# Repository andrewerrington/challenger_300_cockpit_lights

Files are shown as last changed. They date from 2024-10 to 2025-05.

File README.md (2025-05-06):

# challenger_300_cockpit_lights
COCKPIT LIGHTS panels for Challenger 300

DXF files for making the panels. Pilot panel requires one dual concentric potentiometer, two regular potentiometers, and one SR16 2-pos rotary
switch. Also, OpenSCAD files for producing knobs.

Arduino code to interface with X-Plane is included.

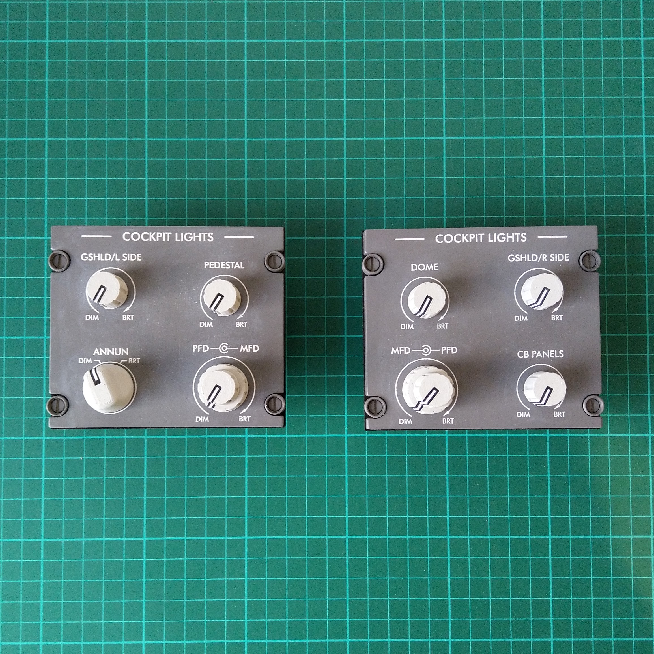
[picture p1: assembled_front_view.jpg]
Glamour shot of finished panels


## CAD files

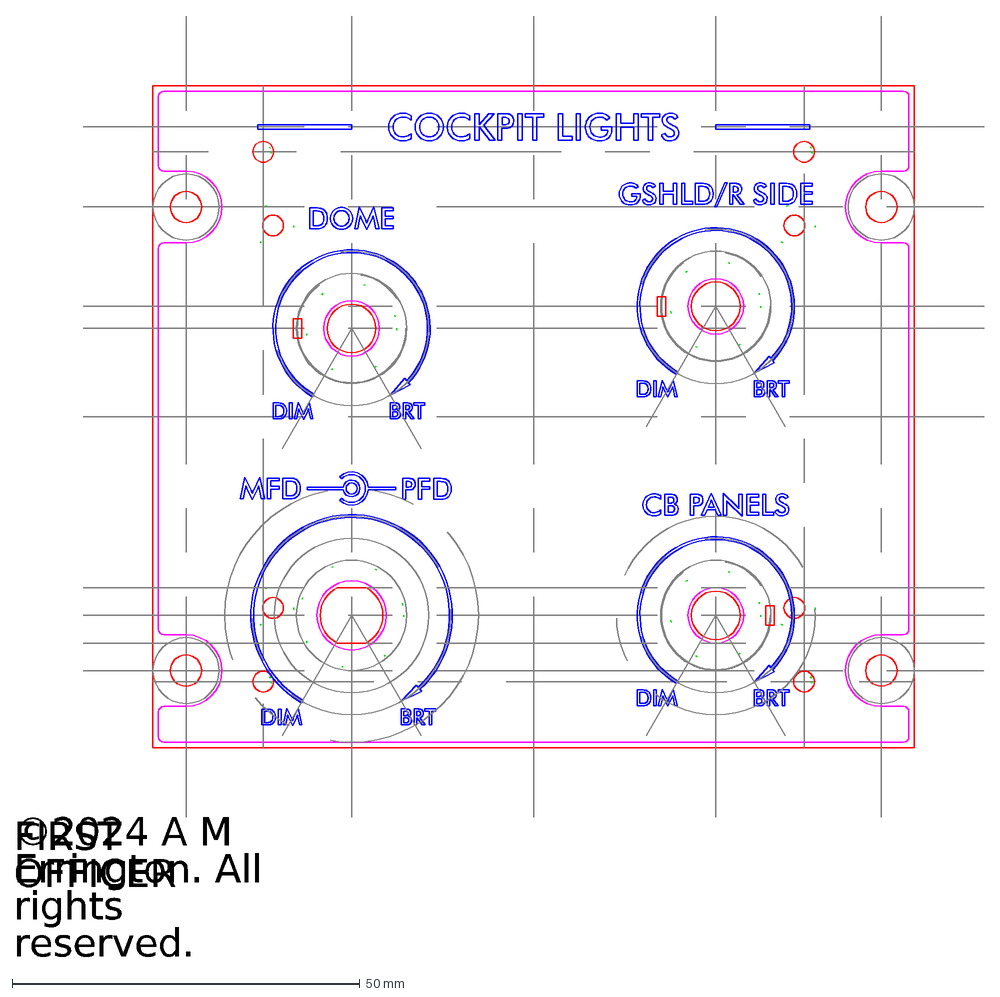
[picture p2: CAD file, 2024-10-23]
COCKPIT_LIGHTS_fo.dxf
FIRST OFFICER
©2024 A M Errington. All rights reserved.

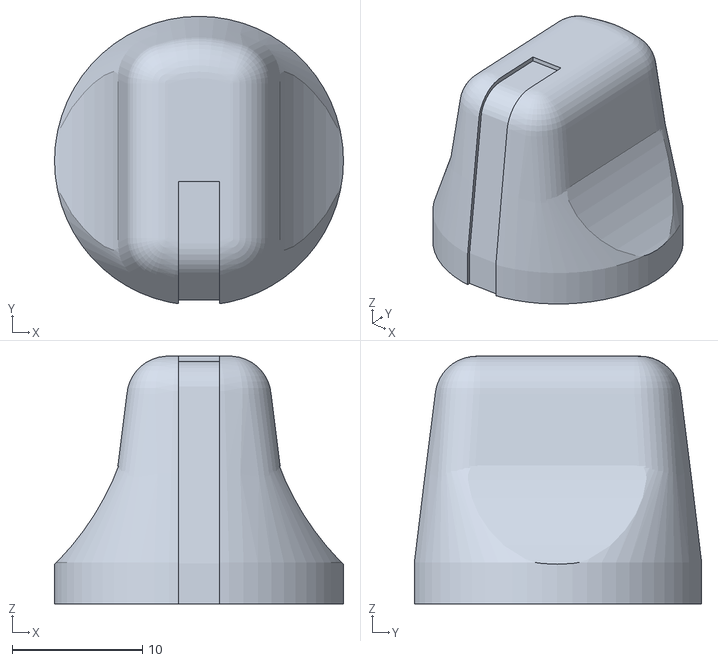
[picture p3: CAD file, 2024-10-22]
knobs/tl8503.stl
22.2 x 22.1 x 19.0

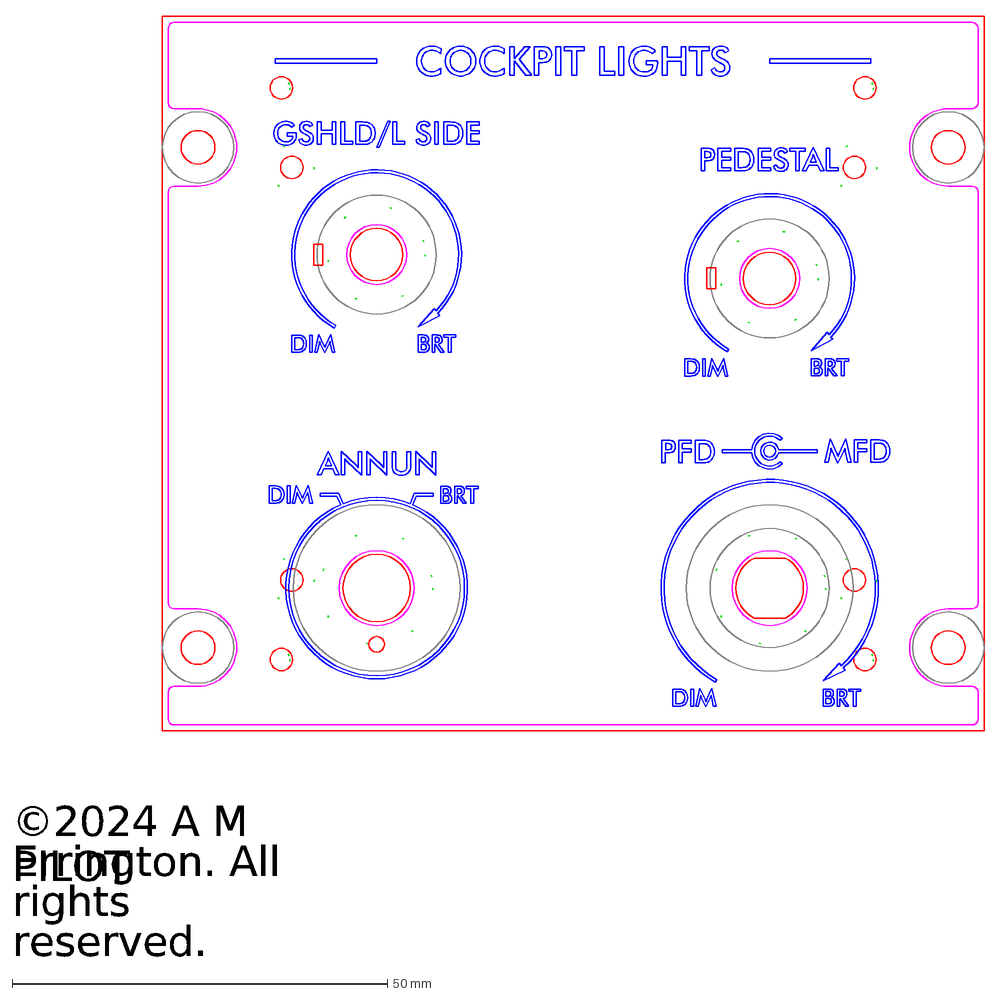
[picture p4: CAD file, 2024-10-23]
COCKPIT_LIGHTS_pilot.dxf
PILOT
©2024 A M Errington. All rights reserved.

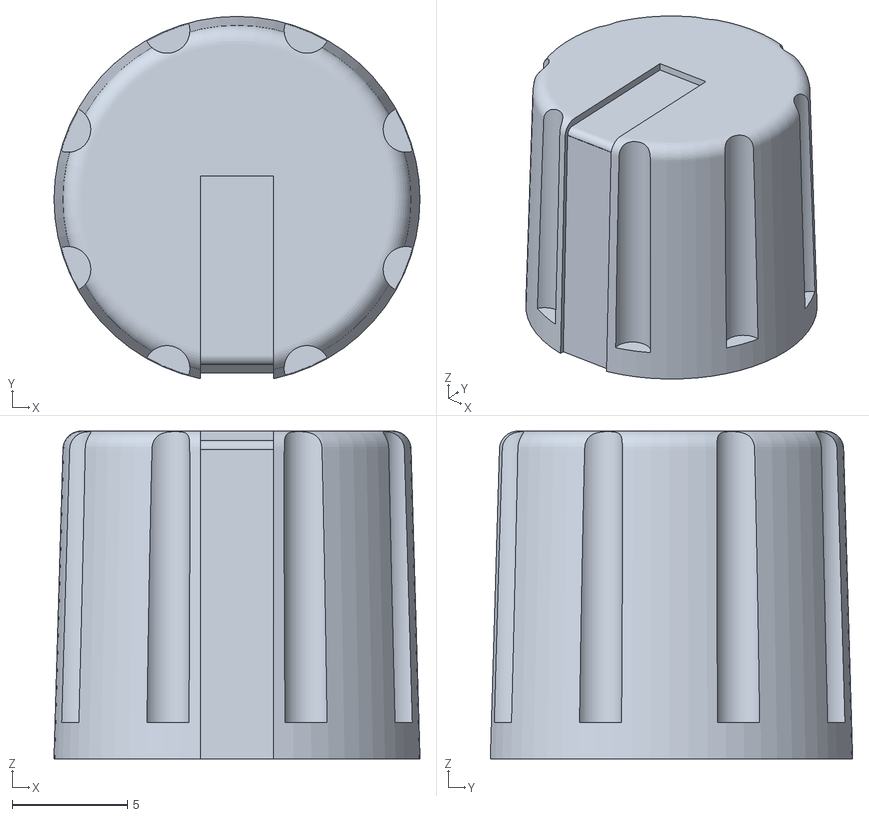
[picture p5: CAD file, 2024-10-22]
knobs/re459_18_spline.stl
15.9 x 15.7 x 14.2

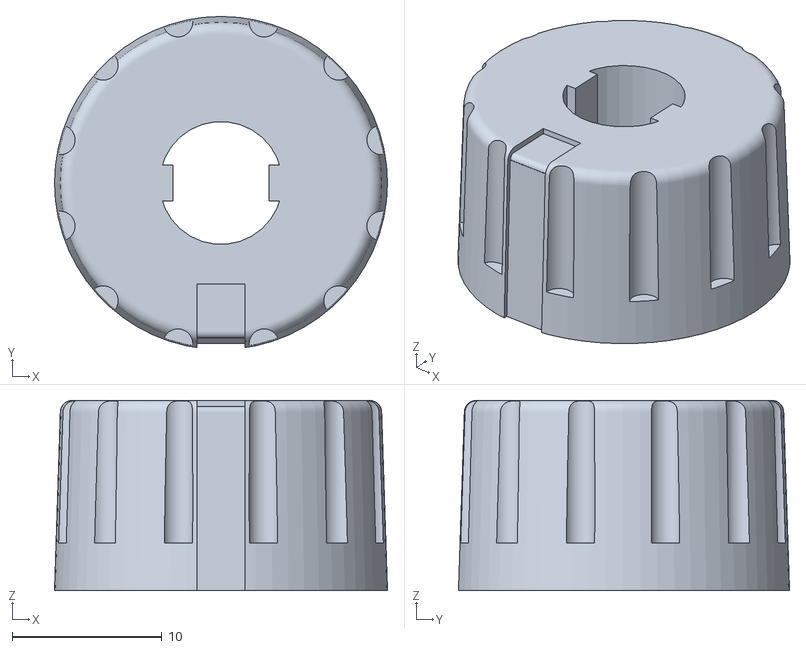
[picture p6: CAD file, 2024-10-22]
knobs/rc4480.stl
22.2 x 22.1 x 12.7

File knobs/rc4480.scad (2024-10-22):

// Based on https://ehcknobs.com/rc4480.html

module torus(major_r, minor_r, theta=360){
    // Edge rounding using a torus
    rotate_extrude(angle=theta, convexity=10, $fn=60)
    translate([major_r+0.01, 0, 0])
    circle(r=minor_r, $fn=40);
}

function to_mm(x) = x * 25.4;

module rc4480(){

  // Body slopes up from 7/8" at the base to 27/32"
  // at the top, 0.5", with an r1/32" round on
  // the top edge and 12 flutes.
  
  difference(){
  // Body
  hull(){
  cylinder(d=to_mm(7/8),h=0.1,$fn=60);
  translate([0,0,to_mm((0.50)-(1/32))])  
  intersection(){
    torus(to_mm((27/32)-(1/32)-(1/32))/2,to_mm(1/32));
  }
}

    // Remove 12 indents around the perimeter
    for(i=[0:11]){
      rotate([0,0,(i*30)+15])
      translate([to_mm(7/8)/2,0,to_mm((1/8))])
      cylinder(d=to_mm(5/64),h=20,$fn=60); 
    }

  // Inset for label
  // Front slope
  translate([-to_mm(1/16),(-to_mm(7/8)/2)-0.5,0])
  rotate([-1.8,0,0])
  cube([to_mm(1/8),0.5+0.4,20]);
  // Top
  translate([-to_mm(1/16),(-to_mm(7/8)/2),to_mm(0.5)-0.4])
  cube([to_mm(1/8),to_mm((7/8)-0.53)/2,5]);
  // Top edge
  translate([-to_mm(1/16),(-to_mm(27/32)/2)+to_mm(1/32),to_mm((0.5)-(1/32))])
  rotate([0,90,0])
  difference(){
    cylinder(r=to_mm(1/32)+0.5,h=to_mm(1/8),$fn=20);
    cylinder(r=to_mm(1/32)-0.4,h=to_mm(1/8),$fn=40);
    translate([-5,0,0])
    cube([10,10,10]);
    translate([0,-5,0])
    cube([10,10,10]);
  }

}

} // module()

difference(){
  rc4480();
  // Remove 6mm hole for switch
  // This example is for a dual-gang pot
  cylinder(d=9.5,h=3,$fn=20);
  difference(){
    cylinder(d=8.2,h=20,$fn=30);
    translate([-4.1,-1.2,5.5])
    cube([0.8+0.1,2.4,10]);
    translate([3.2,-1.2,5.5])
    cube([0.8+0.1,2.4,10]);
  }

}

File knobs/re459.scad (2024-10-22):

// Based on https://ehcknobs.com/re459.html

module torus(major_r, minor_r, theta=360){
    // Edge rounding using a torus
    rotate_extrude(angle=theta, convexity=10, $fn=60)
    translate([major_r+0.01, 0, 0])
    circle(r=minor_r, $fn=40);
}

function to_mm(x) = x * 25.4;

module re459(){

  // Body slopes up from 5/8" at the base to 19/32"
  // at the top, 0.56", with an r1/32" round on
  // the top edge and 8 flutes.
  
  difference(){
  // Body
  hull(){
  cylinder(d=to_mm(5/8),h=0.1,$fn=60);
  translate([0,0,to_mm((0.56)-(1/32))])  
  intersection(){
    torus(to_mm((19/32)-(1/32)-(1/32))/2,to_mm(1/32));
  }
}

    // Remove 8 indents around the perimeter
    for(i=[0:7]){
      rotate([0,0,(i*45)+22.5])
      translate([to_mm(5/8)/2,0,to_mm((1/16))])
      cylinder(d=to_mm(5/64),h=20,$fn=60); 
    }

  // Inset for label
  // Front slope
  translate([-to_mm(1/16),(-to_mm(5/8)/2)-0.5,0])
  rotate([-1.6,0,0])
  cube([to_mm(1/8),0.5+0.4,20]);
  // Top (goes 0.04" past centre)
  translate([-to_mm(1/16),(-to_mm(7/8)/2),to_mm(0.56)-0.4])
  cube([to_mm(1/8),to_mm((7/16)+0.04),5]);
  // Top edge
  translate([-to_mm(1/16),(-to_mm(19/32)/2)+to_mm(1/32),to_mm((0.56)-(1/32))])
  rotate([0,90,0])
  difference(){
    cylinder(r=to_mm(1/32)+0.5,h=to_mm(1/8),$fn=20);
    cylinder(r=to_mm(1/32)-0.4,h=to_mm(1/8),$fn=40);
    translate([-5,0,0])
    cube([10,10,10]);
    translate([0,-5,0])
    cube([10,10,10]);
  }
}

} // module()

difference(){
  re459();
  // Remove 6mm hole for switch
  //translate([0,0,-0.1])
  //cylinder(r=3,h=7+0.1,$fn=72);
  // 18-spline shaft
  translate([0,0,-0.1])
  cylinder(r=2.83,h=7+0.1,$fn=72);
  for(i=[0:17]){
      rotate([0,0,(i*20)])
      translate([2.8,0,-0.1])
      rotate([0,0,45])
      translate([-0.3,-0.3,0])
      #cube([0.6,0.6,7+0.1]); 
    }

}

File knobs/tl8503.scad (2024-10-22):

// Based on https://ehcknobs.com/tl8503.html

module torus(major_r, minor_r, theta=360){
    // Edge rounding using a torus
    rotate_extrude(angle=theta, convexity=10, $fn=60)
    translate([major_r+0.01, 0, 0])
    circle(r=minor_r, $fn=40);
}

function to_mm(x) = x * 25.4;

module tl8503(){
  difference(){
    union(){
  hull() {
  // Base
  cylinder(d=to_mm(7/8),h=to_mm(1/8),$fn=60);


  translate([0,0,to_mm((1/2)-(1/8))])  
  intersection(){
    torus(to_mm((3/4)-(1/8)-(1/16))/2,to_mm(1/8));
    translate([to_mm(-4/32),-to_mm(7/8)/2,-to_mm(1/8)])
    cube([to_mm(4/16),to_mm(7/8),to_mm(1/8)*2]);
  }
  
     // Lower finger grip left 
   translate([-to_mm(4/32),-to_mm((1/2))/2,to_mm((1/2)-(1/8))])
  sphere(r=to_mm(1/8),$fn=40);
  translate([-to_mm(4/32),to_mm((1/2))/2,to_mm((1/2)-(1/8))])
  sphere(r=to_mm(1/8),$fn=40);
   // Lower finger grip right 
   translate([to_mm(4/32),-to_mm((1/2))/2,to_mm((1/2)-(1/8))])
  sphere(r=to_mm(1/8),$fn=40);
  translate([to_mm(4/32),to_mm((1/2))/2,to_mm((1/2)-(1/8))])
  sphere(r=to_mm(1/8),$fn=40);

  }
  
  // Rounded top
  hull(){
  translate([0,0,to_mm((3/4)-(1/8))])  
  intersection(){
    torus(to_mm((3/4)-(1/8)-(1/8))/2,to_mm(1/8));
    translate([to_mm(-3/32),-to_mm(7/8)/2,-to_mm(1/8)])
    cube([to_mm(3/16),to_mm(7/8),to_mm(1/8)*2]);
  }

  // Top edge right
    hull(){
  translate([to_mm(3/32),-to_mm((1/2)-(1/32))/2,to_mm((3/4)-(1/8))])
  sphere(r=to_mm(1/8),$fn=40);
  translate([to_mm(3/32),to_mm((1/2)-(1/32))/2,to_mm((3/4)-(1/8))])
  sphere(r=to_mm(1/8),$fn=40);
    }
  // Top edge left
    hull(){
  translate([-to_mm(3/32),-to_mm((1/2)-(1/32))/2,to_mm((3/4)-(1/8))])
  sphere(r=to_mm(1/8),$fn=40);
  translate([-to_mm(3/32),to_mm((1/2)-(1/32))/2,to_mm((3/4)-(1/8))])
  sphere(r=to_mm(1/8),$fn=40);
    }
    hull(){
        translate([0,0,to_mm((1/2)-(1/8))])  
  intersection(){
    torus(to_mm((3/4)-(1/8)-(1/16))/2,to_mm(1/8));
    translate([to_mm(-4/32),-to_mm(7/8)/2,-to_mm(1/8)])
    cube([to_mm(4/16),to_mm(7/8),to_mm(1/8)*2]);
  }

   // Lower finger grip left 
   translate([-to_mm(4/32),-to_mm((1/2))/2,to_mm((1/2)-(1/8))])
  sphere(r=to_mm(1/8),$fn=40);
  translate([-to_mm(4/32),to_mm((1/2))/2,to_mm((1/2)-(1/8))])
  sphere(r=to_mm(1/8),$fn=40);
   // Lower finger grip right 
   translate([to_mm(4/32),-to_mm((1/2))/2,to_mm((1/2)-(1/8))])
  sphere(r=to_mm(1/8),$fn=40);
  translate([to_mm(4/32),to_mm((1/2))/2,to_mm((1/2)-(1/8))])
  sphere(r=to_mm(1/8),$fn=40);
}  
 }  // hull() 
 } // union()

  // Inset for label
  // Base
  translate([-to_mm(1/16),(-to_mm(7/8)/2)-0.5,0])
  cube([to_mm(1/8),0.5+0.4,5]);
  // Front slope
  translate([-to_mm(1/16),(-to_mm(7/8)/2)-0.5,to_mm(1/8)])
  rotate([-7.2,0,0])
  cube([to_mm(1/8),0.5+0.4,20]);
  // Top. Starts ~1/16" away from centre.
  translate([-to_mm(1/16),(-to_mm(7/8)/2),to_mm(3/4)-0.4])
  cube([to_mm(1/8),to_mm((7/16)-(1/16)),5]);
  // Top edge
  translate([-to_mm(1/16),(-to_mm(3/4)/2)+to_mm(1/8),to_mm((3/4)-(1/8))])
  rotate([0,90,0])
  difference(){
    cylinder(r=to_mm(1/8)+0.5,h=to_mm(1/8),$fn=20);
    cylinder(r=to_mm(1/8)-0.4,h=to_mm(1/8),$fn=40);
    translate([-5,0,0])
    cube([10,10,10]);
    translate([0,-5,0])
    cube([10,10,10]);
  }
  difference(){
    translate([to_mm(66/64),-20,to_mm(46/64)])
  rotate([-90,0,0])
  cylinder(r=to_mm(27/32),h=40,$fn=90);
  translate([0,-40,10.6])
   cube([80,80,80]);
  }
  difference(){
    translate([-to_mm(66/64),-20,to_mm(46/64)])
  rotate([-90,0,0])
  cylinder(r=to_mm(27/32),h=40,$fn=90);
  translate([-80,-40,10.6])
   cube([80,80,80]);
  }

  /*
  difference(){
  translate([to_mm(30/32),0,to_mm(24/32)])
  sphere(r=to_mm(26/32),$fn=60);
  translate([0,-40,10.6])
   cube([80,80,80]);
  }
  */
  } // difference()
} // module()

difference(){
  tl8503();
  // Remove 6mm hole for switch
  translate([0,0,0])
  cylinder(d=6,h=7.5,$fn=20);
}

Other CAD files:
knobs/re459.stl

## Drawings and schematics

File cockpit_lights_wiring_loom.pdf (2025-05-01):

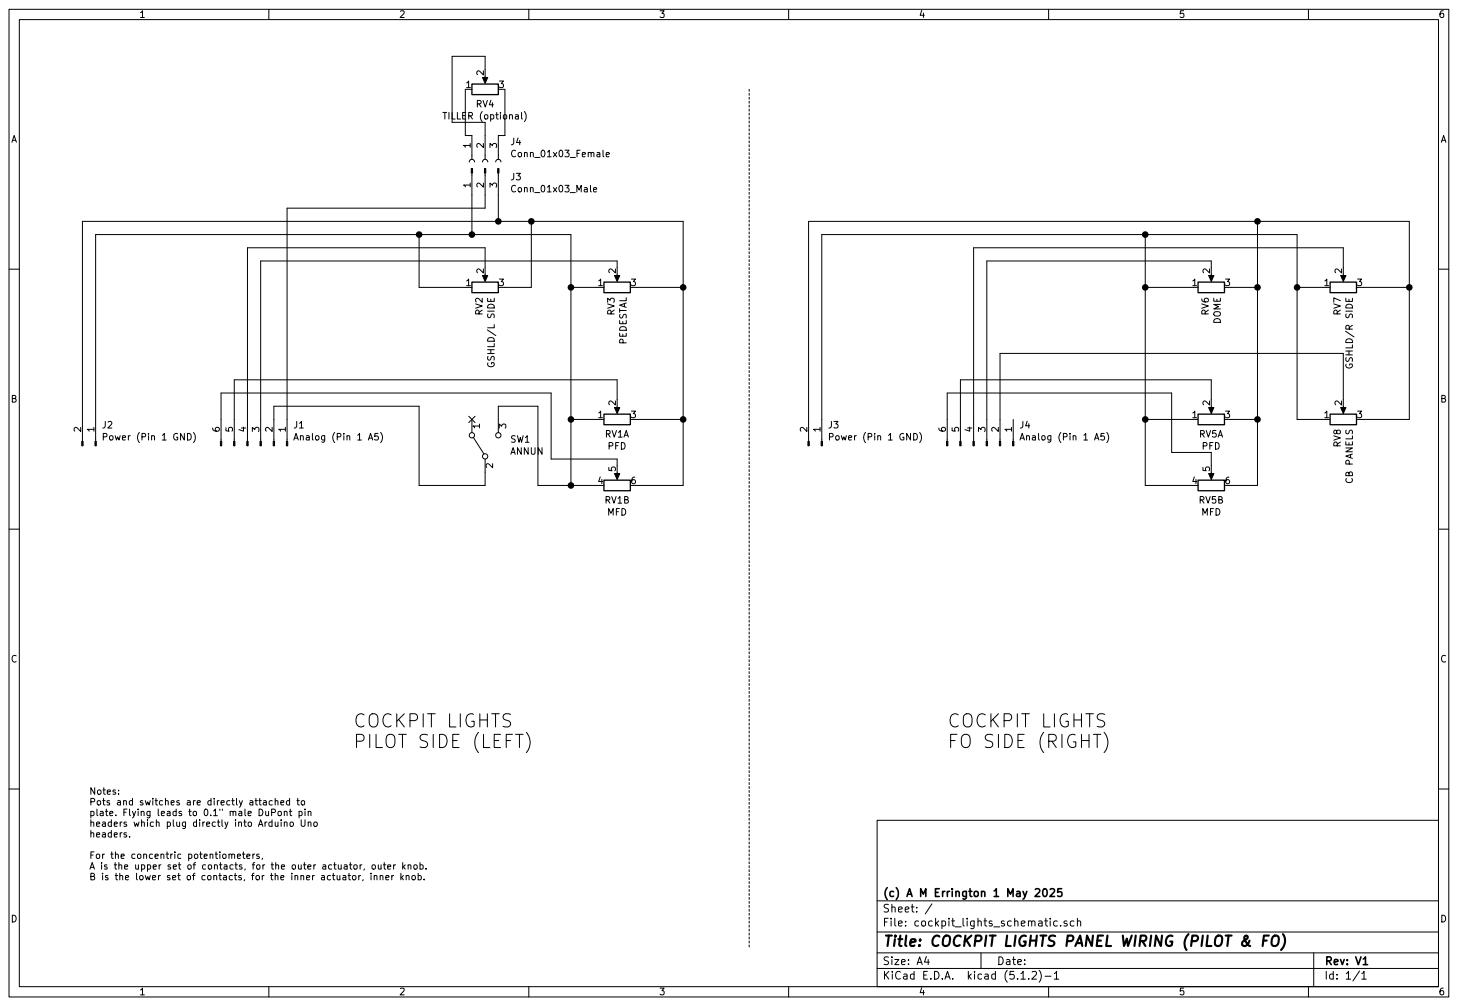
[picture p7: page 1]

3 RV2 GSHLD/L SIDE Notes: Pots and switches are directly attached to

plate. Flying leads to 0.1" male DuPont pin
headers which plug directly into Arduino Uno
headers. For the concentric potentiometers,

A is the upper set of contacts, for the outer actuator, outer knob. B is the lower set of contacts, for the inner actuator, inner knob.

File: cockpit_lights_schematic.sch Sheet: / (c) A M Errington 1 May 2025

Id: 1/1 Title: COCKPIT LIGHTS PANEL WIRING (PILOT & FO)

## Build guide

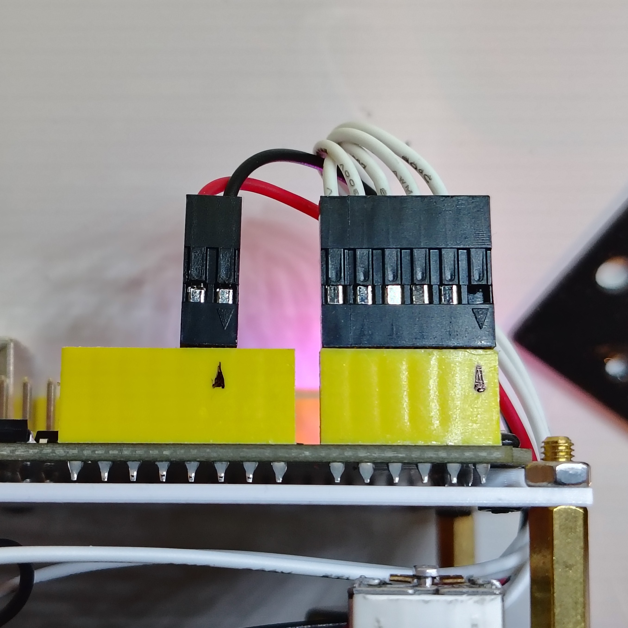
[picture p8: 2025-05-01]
wiring_loom_connection.jpg

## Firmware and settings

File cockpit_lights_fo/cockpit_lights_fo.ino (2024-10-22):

/*
   COCKPIT LIGHTS - First Officer side

   Based on ardxp framework

   version 0.1  October 2024

   Copyright (c) October 2024 A M Errington

   Arduino Nano and Wiznet W5500 Ethernet module to handle the First Officer
   side COCKPIT LIGHTS panel. This panel is located by the First Officer's
   right elbow and contains 5 potentiometers to control the brightness of
   various things in the cockpit.

*/

//        1         2         3         4         5         6         7
// 34567890123456789012345678901234567890123456789012345678901234567890123456789

// Support for Wiznet W5500 Ethernet module
#include <SPI.h>
#include <Ethernet.h>
#include <EthernetUdp.h>

// Ethernet MAC address, must be unique for all devices on network.
byte mac[] = { 0xDE, 0xAD, 0xBE, 0xEF, 0xFE, 0xED };


// This code uses DHCP. Your network should assign an IP address to this unit.
// Alternatively, check the Arduino Ethernet examples to show how to set a
// fixed IP address in this code.

// This code also listens for the X-Plane multicast beacon to get the IP
// address and port of the X-Plane PC. If you can't use the beacon, then set
// the IP address of your X-Plane PC on the network here, set xplane_port to
// the default 49000, or whatever you use, and remove the beacon code.
IPAddress xplane_ip(0,0,0,0); // Overwritten by the beacon address later.
unsigned int xplane_port = 0; // X-Plane listens to us on this port.

IPAddress BECN_ip(239,255,1,1); // UDP multicast address for X-Plane beacon.
unsigned int BECN_port = 49707; // X-Plane beacons on this port (was 49000).

unsigned int localPort = 49094; // local port we'll listen on (can be any port).

// An EthernetUDP instance to let us send and receive packets over UDP.
EthernetUDP udp;

// Buffer for receiving and sending UDP data.
char packetBuffer[512];
int packetSize; // Varible to hold received packet size

// A union to convert between bytes and floats
union u_tag {
  byte bin[4];
  float num;
} u;

// Your variables and libraries here

// Analog inputs on COCKPIT LIGHTS First Officer side panel

// General variable for incoming pot values
int16_t pot_value = 0;

// Zone 3 brightness. This is the top right potentiometer, labelled
// GSHLD/R SIDE. It controls the brightness of the right glareshield, and
// the FO's DCP. This is connected to the dataref "cl300/gshldr_h"
const int zone_3_pot = A2;  
int16_t last_zone_3_pot_value = -100;

// Zone 4 brightness. This is the bottom right potentiometer, labelled
// CB PANELS. It controls the brightness of the contact breaker panels.
// This is connected to the dataref "cl300/cbp_h"
const int zone_4_pot = A4;  
int16_t last_zone_4_pot_value = -100;

// FO's PFD and MFD brightness. These are a pair of concentric potentiometers
// at the bottom left which control the brightness of the FO's displays.
// These are connected to "cl300/cpfd_h" and "cl300/cmfd_h".
const int fo_PFD_pot = A1;  
const int fo_MFD_pot = A0;  

uint16_t last_fo_PFD_pot_value = -100;
uint16_t last_fo_MFD_pot_value = -100;

// Dome light brightness. This is the top left potentiometer, labelled
// DOME. It controls the brightness of the overhead dome light.
// This is connected to the dataref "cl300/dome_h"
const int dome_pot = A3;
int16_t last_dome_pot_value = -100;


// -----------------------------------------------------------------------------

// X-Plane UDP routines

int sendUDP(uint16_t n_bytes) {
  // Send a UDP packet of length 'n_bytes' to X-Plane
  udp.beginPacket(xplane_ip, xplane_port);
  udp.write(packetBuffer, n_bytes);
  return udp.endPacket();
}

void subscribeDataref(const char* dataref, uint16_t freq_Hz, uint8_t index) {
  // Create and send UDP packet to subscribe to a dataref.
  // First argument is a PSTR()
  // e.g.
  // subscribeDataref(PSTR("sim/cockpit2/switches/panel_brightness_ratio[0]"),4,1);
  // This would subscribe to "sim/cockpit2/switches/panel_brightness_ratio[0]"
  // at a frequency of 4Hz, and an index of 1. Later, the simulator will send
  // an RREF packet with an index of 1, so we know the accompanying float
  // value is for "sim/cockpit2/switches/panel_brightness_ratio[0]".

  // General subscription packet is of the form
  // "RREF\x00aaaabbbbpath\to\dataref"
  // Where aaaa is a 32-bit integer representing the desired reporting frequency
  // and bbbb is a 32-bit integer used as an index to tag incoming data so that
  // we know which dataref it refers to. Here they are limited to 8 bits.
  
  // Clear the packet buffer.
  memset(packetBuffer, 0, sizeof(packetBuffer));
  // Build the request in the packet buffer.
  strcpy_P(packetBuffer, PSTR("RREF"));
  memcpy(packetBuffer + 5, &freq_Hz, sizeof(freq_Hz));
  memcpy(packetBuffer + 9, &index, sizeof(index));
  strcpy_P(packetBuffer + 13, dataref);
  sendUDP(413); // Subscription packet is 413 bytes.
}

void writeDataref(const char* dataref, float val) {
  // Create and send UDP packet to write a float value to a dataref.
  // First argument is a PSTR()
  // e.g.
  // writeDataref(PSTR("sim/cockpit2/switches/panel_brightness_ratio[0]"),0.5);

  // General write dataref packet is of the form
  // "DREF\x00nnnnpath\to\dataref"
  // Where nnnn is a 32-bit float to be written to the dataref.

  // Clear the packet buffer
  memset(packetBuffer, 0, sizeof(packetBuffer));
  // Build the request in the packet buffer.
  strcpy_P(packetBuffer, PSTR("DREF"));
  memcpy(packetBuffer + 5, &val, sizeof(val));
  strcpy_P(packetBuffer + 9, dataref);
  sendUDP(509); // Dataref packet is 509 bytes.
}

void sendCommand(const char* command) {
  // Create and send UDP packet to for an X-Plane command.
  // Argument is a PSTR()
  // e.g.
  // sendCommand(PSTR("sim/annunciator/clear_master_caution"));

  // General command packet is of the form
  // "CMND\x00path\to\command\x00"

  // No need to clear the packet buffer as we will send exactly what we put in.
  // Build the command in the packet buffer. PSTR contains the trailing \x00.
  strcpy_P(packetBuffer, PSTR("CMND"));
  strcpy_P(packetBuffer + 5, command);
  sendUDP(strlen_P(command) + 6); // Command packet is only as long as needed.
}

void setup() {
  // You'll probably need a serial port open for debugging.
  Serial.begin(115200);
  while (!Serial) {
    ; // wait for serial port to connect. Needed for native USB port only
  }
  Serial.println(F("Challenger 300 - COCKPIT LIGHTS, First Officer"));
  Serial.println(F("V0.1 October 2024"));

  // Set up Ethernet
  // Times out after about 1 minute if no DHCP server responds.
  Serial.println(F("Setting up Ethernet."));
  Serial.print(F("MAC address: "));
  for (byte i = 0; i < 6; ++i) {
    if (mac[i] < 0x0F) Serial.print(F("0"));
    Serial.print(mac[i], HEX);
    if (i < 5)
      Serial.print(F(":"));
  }
  Serial.println();

  Serial.println(F("Waiting for DHCP."));
  Ethernet.begin(mac);
  
  Serial.print(F("IP address: "));
  Serial.println(Ethernet.localIP());

  // If you don't want to listen for a BECN packet you could store your
  // X-Plane PC IP address in EEPROM, or hard-code it.

  // This code will listen for the current BECN and capture the IP address
  // of the X-Plane PC, and the port number it is listening on, but only
  // if the PC role is '1'. See X-Plane UDP documentation for more info.
  // We don't check the reported version number for compatibility. At some
  // point in the future things will break. Sorry.

  Serial.println(F("Listening for multicast beacon."));
  udp.beginMulticast(BECN_ip, BECN_port);

  while (true){
    packetSize = udp.parsePacket();
    if (packetSize){
      Serial.print(F("Received packet of size "));
      Serial.println(packetSize);
      udp.read(packetBuffer, packetSize);

      if (strncmp(packetBuffer, "BECN\x00", 5) == 0) {
        Serial.println(F("Packet is BECN."));
        
        // role is a 32 bit unsigned integer, but only has values of 1, 2,
        // or 3, so we will just look at the low byte. We are looking for
        // the master PC, which has a role of 1.

        if (packetBuffer[15]==1) {
          Serial.println(F("Role is 1."));

          // Keep the IP address of the X-Plane PC
          xplane_ip = udp.remoteIP();
          Serial.print(F("X-Plane IP: "));
          Serial.println(xplane_ip);

          // Keep the port number the X-Plane PC is using
          memcpy(&xplane_port,packetBuffer+19,2);
          Serial.print(F("X-Plane port: "));
          Serial.println(xplane_port);
          
          // We have the address and port, break out.
          // Otherwise loop forever, because we don't know the address of the
          // X-Plane PC.
          break;
        }
      }
    }
    delay(10);
  }

  // start UDP
  udp.begin(localPort);

  // Power-on test
  Serial.println(F("Self test."));
  // Do some self-test code here if needed.

  Serial.println(F("Self test done."));

  // Unsubscribe in case we have been reset.
  // Unsubscribe is the same as subscribing, but with a frequency of 0.
  Serial.println(F("Unsubscribing from datarefs."));
  //subscribeDataref(PSTR("cl300/mast_warn"), 0, 0x01);
  //subscribeDataref(PSTR("cl300/mast_caut"), 0 , 0x02);
  //subscribeDataref(PSTR("cl300/gshldl"), 0, 0x03);
  //subscribeDataref(PSTR("cl300/gshldr"), 0, 0x04);

  // Subscribe to the datarefs you want, setting the frequency you'd like to
  // receive the dataref, and a tag, or index, which you will use later to
  // determine what data you have received.
  Serial.println(F("Subscribing to datarefs."));

  // Subscribe to Master Warning, 20 per second, with an index of 0x01
  //subscribeDataref(PSTR("cl300/mast_warn"), 20, 0x01);

  // Subscribe to Master Caution, 20 per second, with an index of 0x02
  //subscribeDataref(PSTR("cl300/mast_caut"), 20 , 0x02);

  // Subscribe to gshldl, five times per second, with an index of 0x03.
  // This will be Zone1
  //subscribeDataref(PSTR("cl300/gshldl"), 5, 0x03);

  // Subscribe to gshldr, five times per second, with an index of 0x04.
  // This will be Zone3r
  //subscribeDataref(PSTR("cl300/gshldr"), 5, 0x04);

  Serial.println(F("setup() done."));

} // setup()


void loop() {

  // Check for incoming UDP packet
  // COCKPIT LIGHTS doesn't subscribe to any datarefs
  packetSize = udp.parsePacket();

  if (packetSize) {

    // read the packet into packetBuffer
    udp.read(packetBuffer, packetSize);
    
    // The following code is for debugging only.
    Serial.print(F("Received "));
    Serial.print(packetSize);
    Serial.print(F(" byte packet from "));
    Serial.print(udp.remoteIP());
    Serial.print(F(":"));
    Serial.println(udp.remotePort());
    
    Serial.println(F("Contents:"));
    for (int i = 0; i < packetSize; i++) {
      Serial.print((uint8_t)packetBuffer[i], HEX);
      Serial.print(" ");
    
      Serial.println();

      for (int i = 0; i < packetSize; i++) {
        if (packetBuffer[i] < 32) {
          Serial.print("\\x");
          if (packetBuffer[i] < 16) Serial.print("0");
          Serial.print((uint8_t)packetBuffer[i], HEX);
        }
        else
          Serial.print(packetBuffer[i]);
      }
      Serial.println();
    }
    // End debug information

    // Look at the contents of the packet.
    // We're only interested in RREF packets.
    if (strncmp(packetBuffer, "RREF", 4) == 0) {
      // Start at position 5 and unpack the rest
      for (int i = 5; i < packetSize; i += 8) {
        // Unpack the dataref value. It's always a float, so assemble these
        // four bytes into a float
        u.bin[0] = packetBuffer[i + 4];
        u.bin[1] = packetBuffer[i + 5];
        u.bin[2] = packetBuffer[i + 6];
        u.bin[3] = packetBuffer[i + 7];
        float out = u.num;
        // Check the index value, which will be whatever we used when
        // subscribing. It's a 32-bit value, but we only need the first
        // byte as we will only subscribe to a small number of items.

        switch (packetBuffer[i]) {
          case 1: // Dataref we tagged with index 0x01
            // Do something with 'out' float value
            break;
          case 2: // Dataref we tagged with index 0x02
            // Do something with 'out' float value
            break;
          case 3: // Dataref we tagged with index 0x03
            // Do something with 'out' float value
            break;
          case 4: // Dataref we tagged with index 0x04
            // Do something with 'out' float value
            break;
            // etc.
          default:
            // The packet doesn't contain any indexes we handle.
            break;
        }
      }
    }
  } // if (packetSize)

  // COCKPIT LIGHTS inputs:
  // GSHLD/R SIDE
  // CB PANELS
  // PFD
  // MFD
  // DOME
  
  // GSHLD/R SIDE (Zone 3)
  pot_value = analogRead(zone_3_pot);
  if (abs(last_zone_3_pot_value - pot_value)>=4){
    writeDataref(PSTR("cl300/gshldr_h"),pot_value/1023.0);
    last_zone_3_pot_value=pot_value;
  }

  // CB PANELS (Zone 4)
  pot_value = analogRead(zone_4_pot);
  if (abs(last_zone_4_pot_value - pot_value)>=4){
    writeDataref(PSTR("cl300/cbp_h"),pot_value/1023.0);
    last_zone_4_pot_value=pot_value;
  }

  // First Officer PFD 
  pot_value = analogRead(fo_PFD_pot);
  if (abs(last_fo_PFD_pot_value - pot_value)>=4){
    writeDataref(PSTR("cl300/cpfd_h"),pot_value/1023.0);
    last_fo_PFD_pot_value=pot_value;
  }

  // First Officer MFD 
  pot_value = analogRead(fo_MFD_pot);
  if (abs(last_fo_MFD_pot_value - pot_value)>=4){
    writeDataref(PSTR("cl300/cmfd_h"),pot_value/1023.0);
    last_fo_MFD_pot_value=pot_value;
  }

  // Dome
  pot_value = analogRead(dome_pot);
  if (abs(last_dome_pot_value - pot_value)>=4){
    writeDataref(PSTR("cl300/dome_h"),pot_value/1023.0);
    last_dome_pot_value=pot_value;    
  }
 

  delay(10);

} // loop()

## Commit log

2024-10-22 Add files via upload
    Arduino code for panels. Requires Arduino and W5500 Ethernet module.
2024-10-22 Add files via upload
    OpenSCAD and generated STL files for COCKPIT LIGHT panels.
    [rc4480.scad, rc4480.stl, re459.scad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]
2025-05-01 Add files via upload
    Wiring diagram and photos.

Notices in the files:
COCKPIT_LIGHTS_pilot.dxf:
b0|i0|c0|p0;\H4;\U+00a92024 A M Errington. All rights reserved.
